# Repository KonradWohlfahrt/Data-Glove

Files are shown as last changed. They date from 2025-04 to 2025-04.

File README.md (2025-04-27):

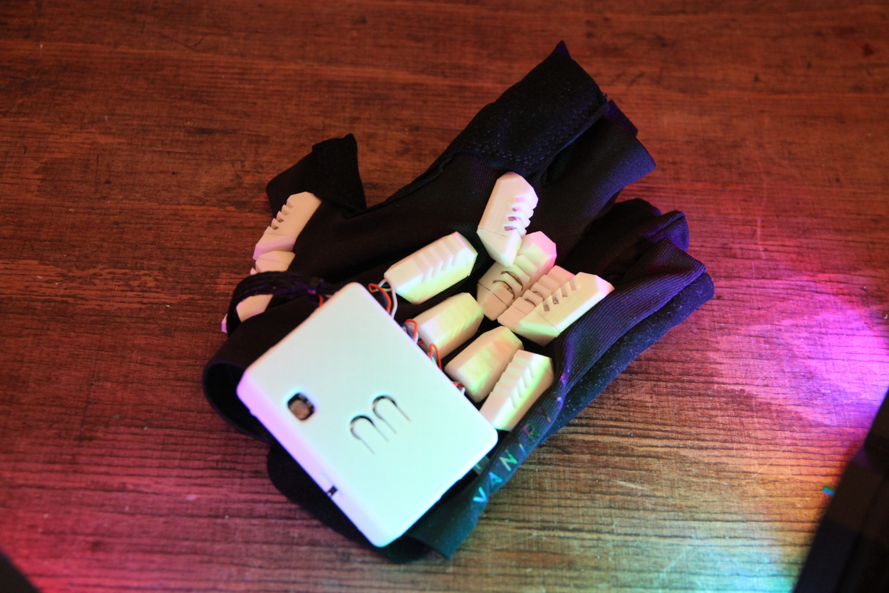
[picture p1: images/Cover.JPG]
Cover


# Data Glove
**In this repository you will find the project files for the Data Glove:** A wearable to control your bluetooth devices by hand movement and gestures. It includes the [XIAO nRF52840](https://www.seeedstudio.com/Seeed-XIAO-BLE-nRF52840-p-5201.html) microcontroller with five hall sensors and a couple of peripherals. A lipo battery makes this project portable while all the components are  mounted on a bicycle glove. Hall sensors vary the output voltage depending on the strength of the magnetic field. Thus, a change of your finger position can be recognized and interpreted by the microcontroller to, for example, send a command to your phone to increase or decrease the volume. The XIAO is very powerful with rich features and libraries. I have included a few examples for you to try out, but expanding upon them and creating your own applications is simple and fast too!
If you want more information and potentially build one yourself too, you can check out the in-depth [blog](https://www.instructables.com/The-Data-Glove-Control-Bluetooth-Devices-With-Gest/) on Instructables.
Finally, the printed circuit boards and the XIAO microcontroller were sponsored by [Seeed Studio](https://www.seeedstudio.com/)! They offer a huge variety of microcontrollers, development boards and services for makers! The XIAO series is a small but powerful set of microcontrollers for any project. The size makes it ideal for tiny battery powered iot applications or ble controllers! Thanks to Seeed Studio and without further ado let me quickly give you an overview of the project:

***
# Materials:
| Component | Amount | Silkscreen label |
|:---|:---:|---:|
| custom pcb | 1 | - |
| 10k 0805 | 3 | R1, R2, R4 |
| 33r 0805 | 2 | R5, R6 |
| 1k 0805 | 2 | R7, R8 |
| MMBT2222ALT1 | 2 | Q1, Q2 |
| 5mm LED | 1 | LED1 |
| TSOP38238 | 1 | LED2 |
| tactile button 6x6x6mm | 2 | SW1, SW2 |
| vibration motor 10x2.7mm | 1 | J3 |
| LDR | 1 | R3 |
| 50/100mAh lipo battery | 1 | J1 |
| SK12D07VG5 | 1 | U2 |
| XIAO nRF52840 (Sense) | 1 | U1 |
| ph2.0 3pin 90 degree header | 5 | J5-J9 |
| SS49e hall sensor | 5 | - |
| neodymium magnet 8x3mm | 20 | - |
| M2.5x6mm screw and nut | 3 | - |
| a bicycle glove | 1 | - |
| a few cables | - | - |

***
# Schematic and PCB:
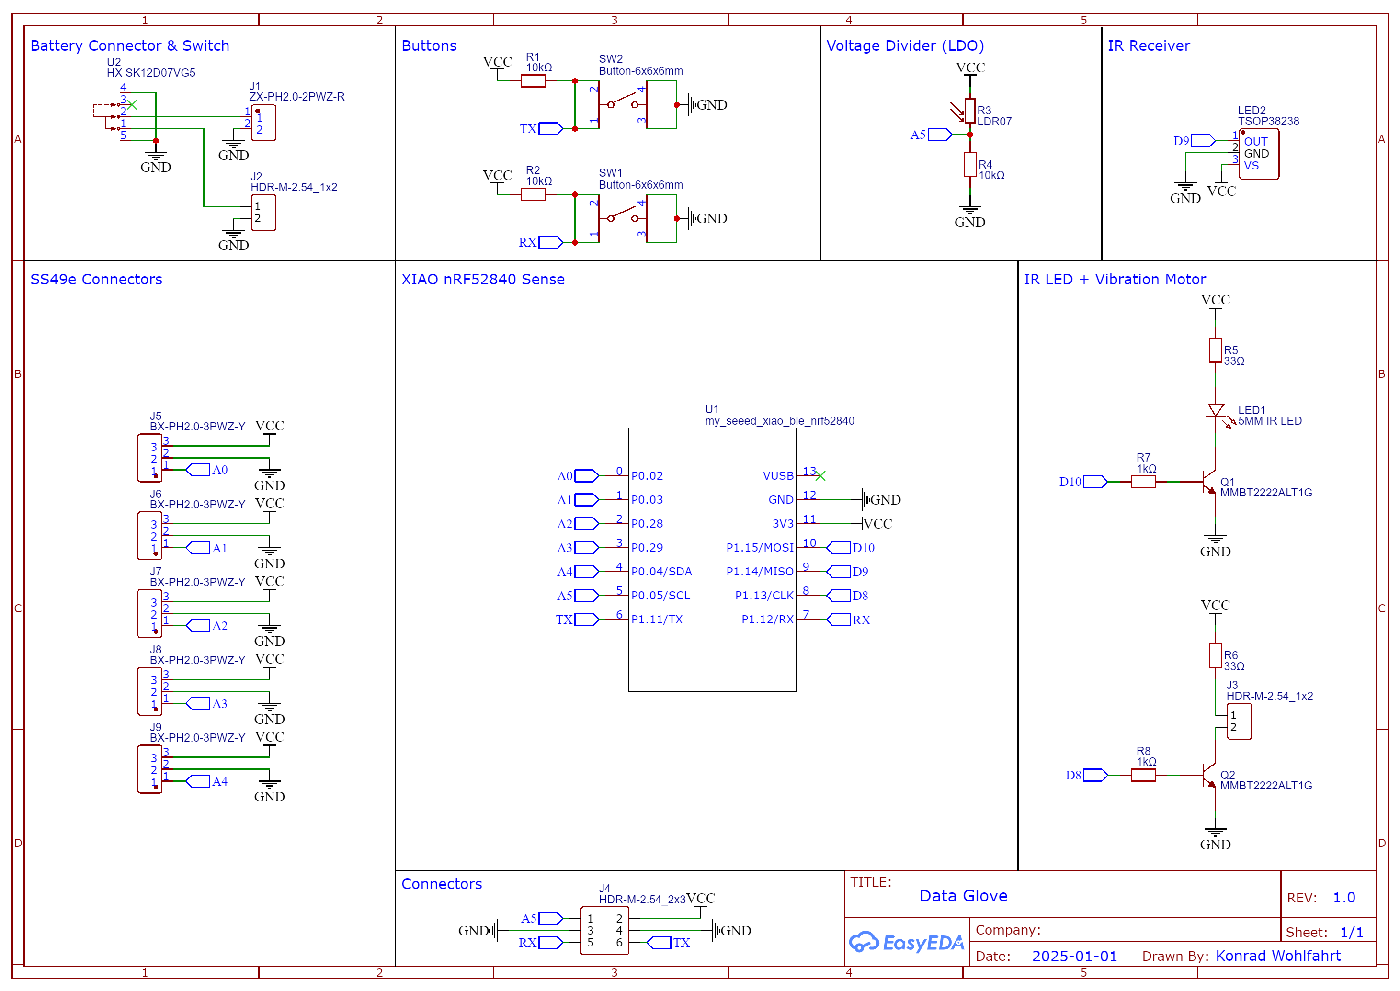
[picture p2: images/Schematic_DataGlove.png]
Schematic

_Schematic_
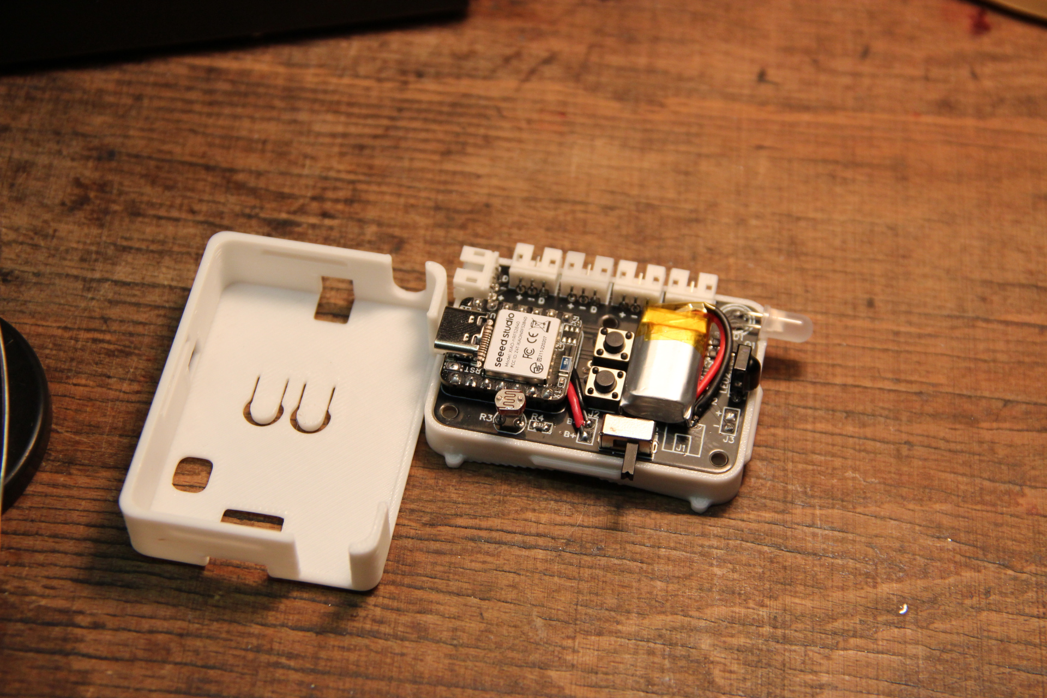
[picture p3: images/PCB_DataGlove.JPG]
PCB

_The soldered pcb inside of the housing_

***
# Programming and Examples
The following wiki shows you how to setup the Arduino IDE for the XIAO boards, it is straightforward and is done quickly: [Wiki](https://wiki.seeedstudio.com/XIAO_BLE/)
You can directly use the usb c port for programming without any other external device, very handy! Those are the following examples:

- `DataGlovePresentation` -> swap presentation pages by using the buttons or contracting and expanding your hand twice (double press)
- `DataGloveMediaControl` -> control music playback; double press to play/pause, long press to skip, buttons for volume
- `DataGloveFlashlight` -> LED illuminates when forming a fist
- `DataGloveCamerashutter` -> take a photo by double pressing

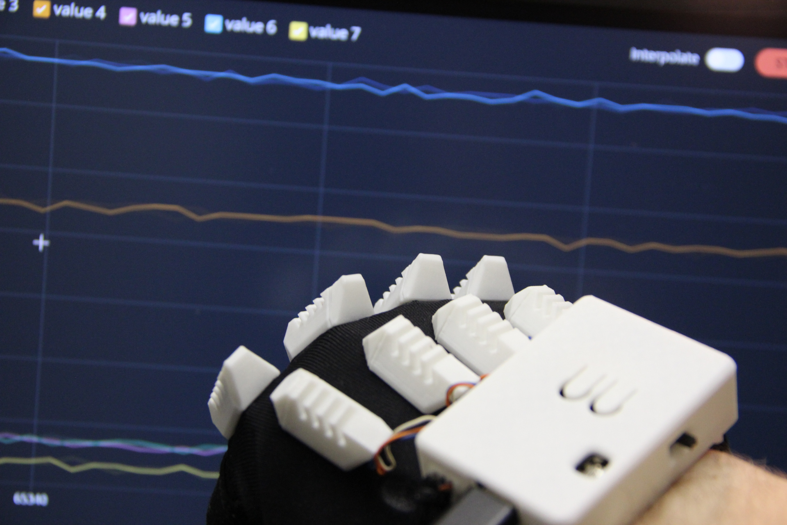
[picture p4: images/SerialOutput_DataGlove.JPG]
Data Glove

_Testing the hall sensors_
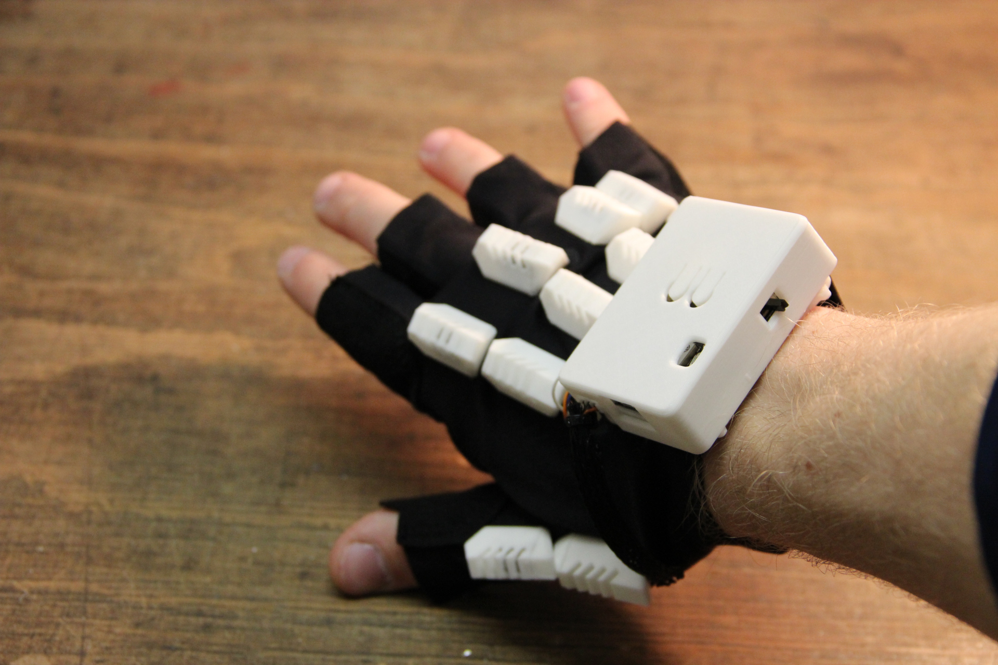
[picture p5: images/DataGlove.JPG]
Data Glove


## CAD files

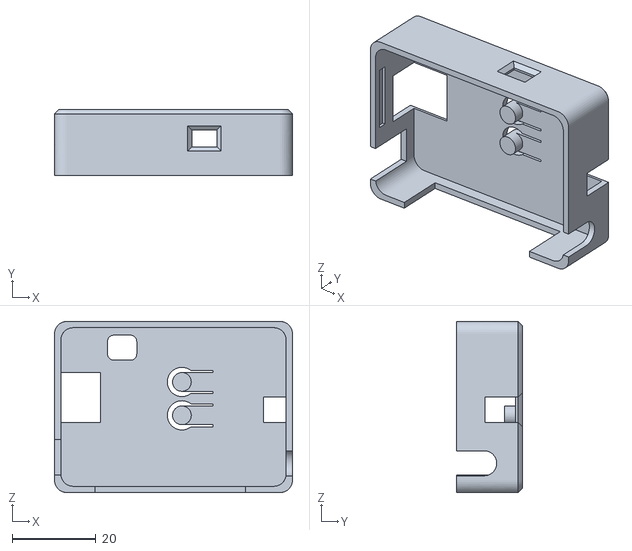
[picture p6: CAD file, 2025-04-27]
cad/PCB Top Cover.stl
57.0 x 15.8 x 41.0

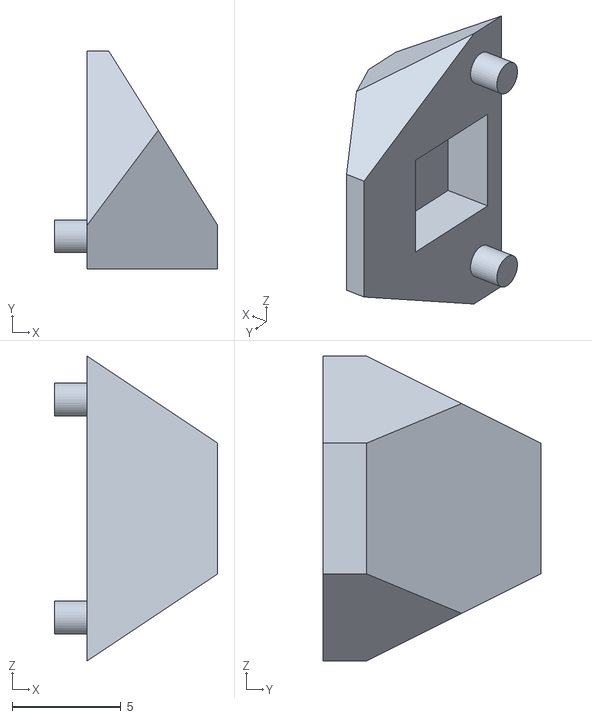
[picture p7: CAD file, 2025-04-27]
cad/Hall Sensor Cover.stl
7.50 x 10.0 x 14.0

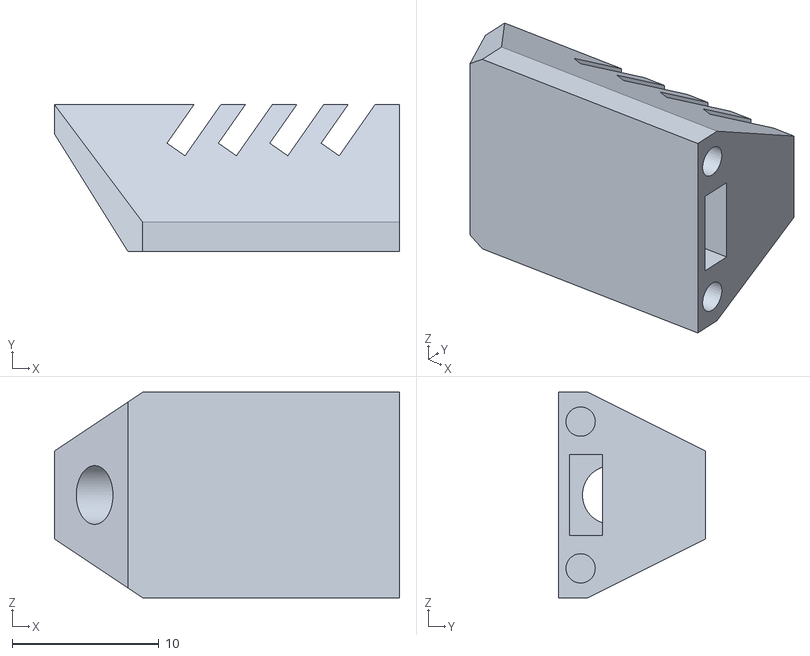
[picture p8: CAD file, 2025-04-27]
cad/Hall Sensor Body.stl
23.5 x 10.0 x 14.0

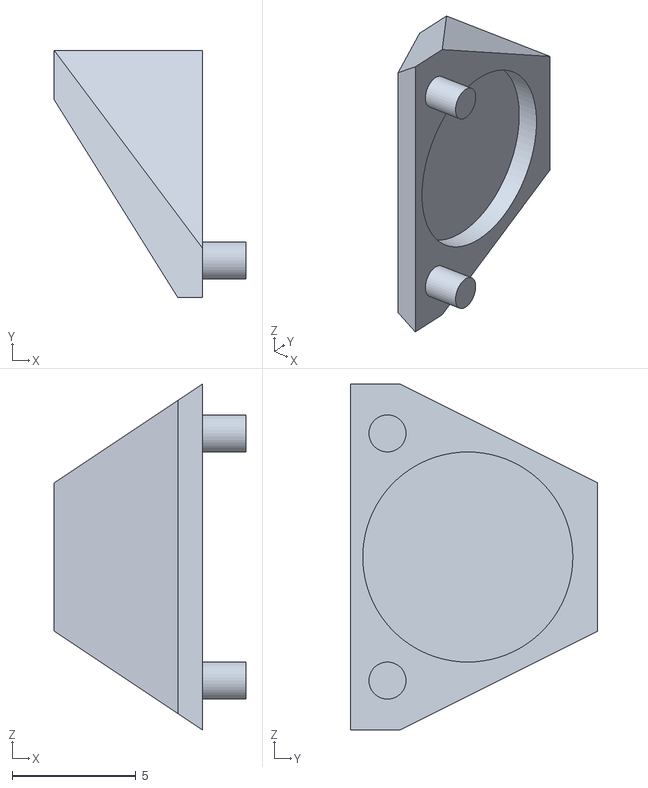
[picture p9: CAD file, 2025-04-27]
cad/Magnet Cover.stl
7.75 x 10.0 x 14.0

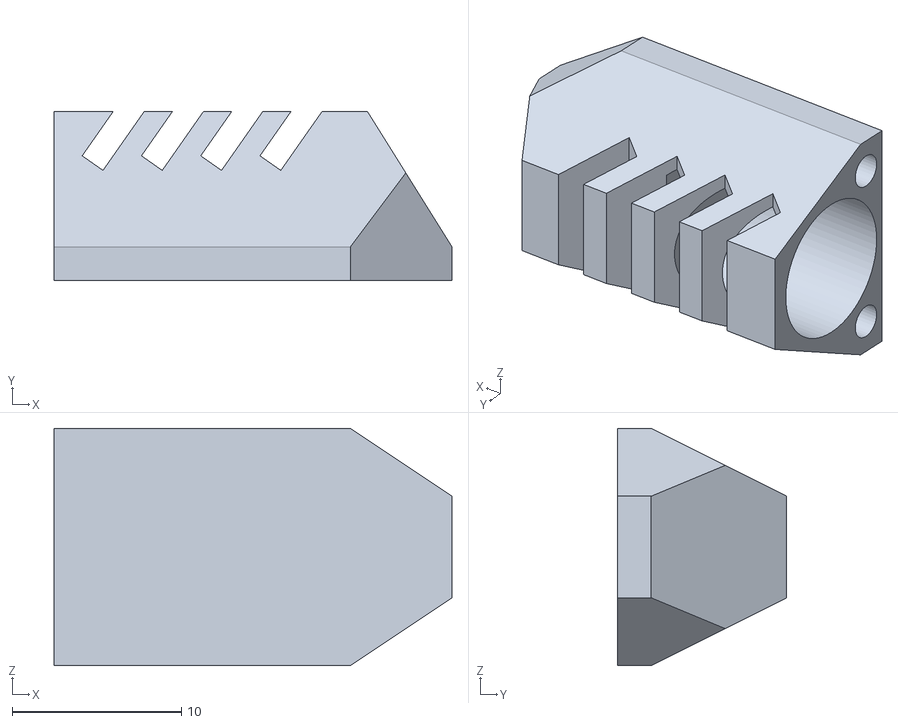
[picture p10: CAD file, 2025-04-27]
cad/Magnet Body.stl
23.5 x 10.0 x 14.0

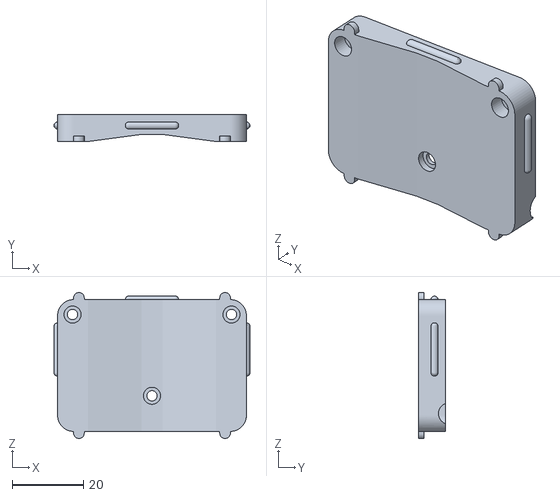
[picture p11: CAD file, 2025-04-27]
cad/PCB Bottom Cover.stl
55.0 x 7.60 x 41.0

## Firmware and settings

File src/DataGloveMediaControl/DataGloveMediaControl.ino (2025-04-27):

#include <bluefruit.h>

#include "preferences.h"

#define LDR_PIN A5
#define VIBRATION_MOTOR_PIN D8
#define LED_PIN D10
#define IR_RECEIVER_PIN D9

#define TOP_BTN_PIN D7
#define BOTTOM_BTN_PIN D6


bool topButton() { return digitalRead(TOP_BTN_PIN) == 0; }
bool bottomButton() { return digitalRead(BOTTOM_BTN_PIN) == 0; }
bool anyButton() { return topButton() || bottomButton(); }


BLEDis bledis;
BLEHidAdafruit blehid;

#define LONG_PRESS_TIME 1500
#define DOUBLE_PRESS_DEADZONE 750
#define DEBOUNCE_TIME 100
unsigned long lastGrip;
bool awaitingDoublePress = false;


void setup() 
{
  pinMode(VIBRATION_MOTOR_PIN, OUTPUT);
  digitalWrite(VIBRATION_MOTOR_PIN, LOW);

  pinMode(TOP_BTN_PIN, INPUT);
  pinMode(BOTTOM_BTN_PIN, INPUT);

  pinMode(HALL_THUMB, INPUT);
  pinMode(HALL_INDEX, INPUT);
  pinMode(HALL_MIDDLE, INPUT);
  pinMode(HALL_RING, INPUT);
  pinMode(HALL_PINKY, INPUT);

  pinMode(LED_RED, OUTPUT);
  pinMode(LED_GREEN, OUTPUT);
  

  Bluefruit.begin();
  Bluefruit.setTxPower(4);

  bledis.setManufacturer("Seeed Studio");
  bledis.setModel("XIAO nRF52840");
  bledis.begin();

  blehid.begin();
  startAdv();

  initializeGlove();
}

void loop() 
{
  // wait for connection
  if (Bluefruit.connected() > 0)
  {
    handleButtons();

    if (handClosed() && millis() - lastGrip > DEBOUNCE_TIME)
    {
      unsigned long timestamp = millis();
      bool longpress = false;
      while (!handOpened()) 
      { 
        if (!longpress && millis() - timestamp > LONG_PRESS_TIME)
        {
          blehid.consumerKeyPress(HID_USAGE_CONSUMER_SCAN_NEXT);
          delay(5);
          blehid.consumerKeyRelease();

          digitalWrite(VIBRATION_MOTOR_PIN, HIGH);
          delay(200);
          digitalWrite(VIBRATION_MOTOR_PIN, LOW);
          longpress = true;
        }
        handleButtons(); 
        delay(5); 
      }
      
      if (millis() - timestamp < DOUBLE_PRESS_DEADZONE && millis() - timestamp > DEBOUNCE_TIME)
      {
        if (!awaitingDoublePress)
          awaitingDoublePress = true;
        else
        {
          blehid.consumerKeyPress(HID_USAGE_CONSUMER_PLAY_PAUSE);
          delay(5);
          blehid.consumerKeyRelease();

          digitalWrite(VIBRATION_MOTOR_PIN, HIGH);
          delay(200);
          digitalWrite(VIBRATION_MOTOR_PIN, LOW);

          awaitingDoublePress = false;
        }
      }
      else
        awaitingDoublePress = false;

      lastGrip = millis();
    }
    if (awaitingDoublePress && millis() - lastGrip > DOUBLE_PRESS_DEADZONE)
      awaitingDoublePress = false;

    digitalWrite(LED_RED, !awaitingDoublePress);
  }
}

void handleButtons() 
{
  if (topButton())
  {
    blehid.consumerKeyPress(HID_USAGE_CONSUMER_VOLUME_DECREMENT);
    delay(5);
    blehid.consumerKeyRelease();
    while (topButton()) delay(5);
  }
  if (bottomButton())
  {
    blehid.consumerKeyPress(HID_USAGE_CONSUMER_VOLUME_INCREMENT);
    delay(5);
    blehid.consumerKeyRelease();
    while (bottomButton()) delay(5);
  }
}

bool handOpened() { readHallSensors(); return fingersExtended[0] && fingersExtended[1] && fingersExtended[2] && fingersExtended[3] && fingersExtended[4]; }
bool handClosed() { readHallSensors(); return !fingersExtended[0] && !fingersExtended[1] && !fingersExtended[2] && !fingersExtended[3] && !fingersExtended[4]; }

void startAdv(void)
{  
  // Advertising packet
  Bluefruit.Advertising.addFlags(BLE_GAP_ADV_FLAGS_LE_ONLY_GENERAL_DISC_MODE);
  Bluefruit.Advertising.addTxPower();
  Bluefruit.Advertising.addAppearance(BLE_APPEARANCE_HID_KEYBOARD);
  
  // Include BLE HID service
  Bluefruit.Advertising.addService(blehid);

  // There is enough room for the dev name in the advertising packet
  Bluefruit.Advertising.addName();
  
  /* Start Advertising
   * - Enable auto advertising if disconnected
   * - Interval:  fast mode = 20 ms, slow mode = 152.5 ms
   * - Timeout for fast mode is 30 seconds
   * - Start(timeout) with timeout = 0 will advertise forever (until connected)
   * 
   * For recommended advertising interval
   * https://developer.apple.com/library/content/qa/qa1931/_index.html   
   */
  Bluefruit.Advertising.restartOnDisconnect(true);
  Bluefruit.Advertising.setInterval(32, 244);    // in unit of 0.625 ms
  Bluefruit.Advertising.setFastTimeout(30);      // number of seconds in fast mode
  Bluefruit.Advertising.start(0);                // 0 = Don't stop advertising after n seconds
}

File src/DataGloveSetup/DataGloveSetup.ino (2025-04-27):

#include <Adafruit_TinyUSB.h> // for serial communication

#include "preferences.h"

#define LDR_PIN A5
#define VIBRATION_MOTOR_PIN D8
#define LED_PIN D10
#define IR_RECEIVER_PIN D9

#define TOP_BTN_PIN D7
#define BOTTOM_BTN_PIN D6


bool topButton() { return digitalRead(TOP_BTN_PIN) == 0; }
bool bottomButton() { return digitalRead(BOTTOM_BTN_PIN) == 0; }
bool anyButton() { return topButton() || bottomButton(); }


void setup() 
{
  Serial.begin(115200);

  while(!Serial) delay(5);

  pinMode(VIBRATION_MOTOR_PIN, OUTPUT);
  digitalWrite(VIBRATION_MOTOR_PIN, LOW);

  pinMode(LED_PIN, OUTPUT);
  digitalWrite(LED_PIN, LOW);

  pinMode(LDR_PIN, INPUT);
  pinMode(IR_RECEIVER_PIN, INPUT);

  pinMode(TOP_BTN_PIN, INPUT);
  pinMode(BOTTOM_BTN_PIN, INPUT);

  pinMode(HALL_THUMB, INPUT);
  pinMode(HALL_INDEX, INPUT);
  pinMode(HALL_MIDDLE, INPUT);
  pinMode(HALL_RING, INPUT);
  pinMode(HALL_PINKY, INPUT);
  
  pinMode(LED_RED, OUTPUT);
  pinMode(LED_GREEN, OUTPUT);
  pinMode(LED_BLUE, OUTPUT);

  digitalWrite(LED_RED, HIGH);
  digitalWrite(LED_GREEN, HIGH);
  digitalWrite(LED_BLUE, HIGH);


  Serial.println("initialization complete!");
  Serial.println("press any button to continue...");
  while (!anyButton()) delay(5);
  

  // EXTENDED VALUES
  Serial.println();
  Serial.println("Open your hand!");
  delay(3000);
  readHallSensors(50);
  int thumb_extended = _sensorData[0];
  int index_extended = _sensorData[1];
  int middle_extended = _sensorData[2];
  int ring_extended = _sensorData[3];
  int pinky_extended = _sensorData[4];
  for (int i = 0; i < 5; i++)
    extendedValues[i] = _sensorData[i];

  // CONTRACTED VALUES
  Serial.println();
  Serial.println("Form a fist!");
  delay(3000);
  readHallSensors(50);
  int thumb_contracted = _sensorData[0];
  int index_contracted = _sensorData[1];
  int middle_contracted = _sensorData[2];
  int ring_contracted = _sensorData[3];
  int pinky_contracted = _sensorData[4];
  for (int i = 0; i < 5; i++)
    contractedValues[i] = _sensorData[i];

  
  Serial.println();
  Serial.println("--- Replace the values in preferences.h with the following ---");

  Serial.print("int extendedValues[5] = { ");
  Serial.print(thumb_extended);
  Serial.print(", ");
  Serial.print(index_extended);
  Serial.print(", ");
  Serial.print(middle_extended);
  Serial.print(", ");
  Serial.print(ring_extended);
  Serial.print(", ");
  Serial.print(pinky_extended);
  Serial.println(" };");

  Serial.print("int contractedValues[5] = { ");
  Serial.print(thumb_contracted);
  Serial.print(", ");
  Serial.print(index_contracted);
  Serial.print(", ");
  Serial.print(middle_contracted);
  Serial.print(", ");
  Serial.print(ring_contracted);
  Serial.print(", ");
  Serial.print(pinky_contracted);
  Serial.println(" };");

  initializeGlove();

  Serial.println();
  Serial.println("press any button to test...");

  while (!anyButton()) delay(5);
}

void loop() 
{
  readHallSensors();
  Serial.print(fingersExtended[(int)finger_thumb]);
  Serial.print('\t');
  Serial.print(fingersExtended[(int)finger_index]);
  Serial.print('\t');
  Serial.print(fingersExtended[(int)finger_middle]);
  Serial.print('\t');
  Serial.print(fingersExtended[(int)finger_ring]);
  Serial.print('\t');
  Serial.println(fingersExtended[(int)finger_pinky]);
}
